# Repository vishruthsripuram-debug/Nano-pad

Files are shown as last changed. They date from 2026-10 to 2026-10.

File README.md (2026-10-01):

# Nano pad
A 4 key macro pad that you can program actions to.
Screenshot 2026-05-01 at 12 41 59 pm

## Design
My inspiration for this macro pad was the printed pad by prota design but i wanted to make something smaller and cheaper than both of their offering the printed pad and glyff. The printed pad being $68 seemed quite unreasonable to me seeing as it was only a screen a few key swicthes and a microcontroller.

I wanted the project to be simple and easily accessible and customisable by many people so all of the PCB design files are included in the rep for download and printing from a pcb service. The case is 3d printable in any colour you like and customisable to include a knob or other features as step and other cad files are included. The model has also been published on makerworld for the ease of use with Bambulab printers. The whole idea is to have a simple good looking macro pad that anyone can own for under $15 USD, for 25 USD you can own 5 macro pads. 

**The design is completely original and simply takes some inspiration fro the prota designs macropad**

## Bill of Materials — Macro Pad

| Item # | Designator | Qty | Manufacturer | Mfg Part # | Description / Value | Package/Footprint | Type | Price Range (AUD / Unit) | Verified Store Links | Notes |
|---|---|---|---|---|---|---|---|---|---|---|
| **1** | SW1, SW2, SW3, SW4 | 4 | Cherry | MX1A-G1NW | MX Brown, tactile, PCB mount, 5-pin | SW_Cherry_MX_1.00u_PCB | THT | $0.40 – $0.88 | [Cafege](https://cafege.com.au "Cherry MX1A-G1NW") <br> [NetNest](https://netnest.com.au "NetNest MX1A-G1NW") <br> [Robot Gear](https://robotgear.com.au "Robot Gear Cherry MX2A Brown") | Sold in packs or individually. Newer MX2A variants are drop-in compatible 5-pin tactile substitutes if the hyperglide variant lacks stock. |
| **2** | U1 | 1 | DFRobot | DFR0648 | Fermion 0.91" 128x32 SSD1306 OLED, I2C, top-mounted pin header (OLED-B) | Module, pin header, THT | THT | $9.90 – $14.50 | [DFRobot Official](https://dfrobot.com "DFRobot DFR0648") <br> [DigiKey](https://digikey.com "DigiKey DFR0648") <br> [Element14 AU](https://element14.com "Element14 DFR0648") | **Double-check pinout prior to soldering**: ensure pins sit on the short top border. |
| **3** | U2 | 1 | Seeed Studio | 101991470 | XIAO ESP32-C6 module (Tape and Reel, SMD variant) | SMD castellated module | SMD | $12.08 – $15.50 | [Pakronics](https://pakronics.com.au "Pakronics Seeed 101991470") <br> [Seeed Studio](https://seeedstudio.com "Seeed Studio 101991470") <br> [RobotShop](https://robotshop.com "RobotShop Seeed 101991470") | Specifically the tape-and-reel edition designed for automated SMT layout without any pre-attached pins. |
| **4** | PCB1 | 1 | Custom | N/A | Main Board PCB | Custom | Board | $1.80 | N/A | Cost per individual board based on production run. |

## Software
software

## Instructions
### Assembly
1. Order the PCB, I ordered with PCBWay and had assembly included.
2. Print out the case.
3. Assemble the PCB, put the OLED into the pin headers and solder it through, Ideally the SMD ESP32 is assembled by PCBWay, but if you can solder SMD then go for it. The keyswitches are through hole solders as well and thats everything.
4. for assembly, insert the board into the case and use m3x 4 BHCS screws to attach the board to the case, the close the lid of the cad, it is a press fit.
5. Click on your keycaps and plug in the macropad

### Flashing
1. Once the board is plugged into your PC, downlaod the code from the github repository, specifically the INO file and open it in Arduino IDE
2. Add ESP32 board support:
File → Preferences → Additional Boards Manager URLs → add:
https://raw.githubusercontent.com/espressif/arduino-esp32/gh-pages/package_esp32_index.json
Tools → Board → Boards Manager → search "esp32" → install "esp32 by Espressif Systems"
3. Select the board
4. Install required libraries (Library Manager, Tools → Manage Libraries):
Adafruit GFX / relevant OLED driver library for your DFRobot module (name it specifically once confirmed)
Any keyboard/HID library
5. Press the upload button and then your done

### Setup
1. Downlaod and open the html file
2. connect your board
3. select the desired functions for your macropad
4. save and uppload
5. exit
6. Youre all done :)

## Schematic and PCB images
Screenshot 2026-09-15 at 11 06 41 AM


## Credits
In collaboration with PCBWay

**PCBWay has financially sponsored the project by providin the parts and assembly free of cost**

The keycaps used in this project are the simple cherry mx keycaps by 3dnerdcave on printables
https://www.printables.com/model/118708-simple-cherry-mx-keycap/files

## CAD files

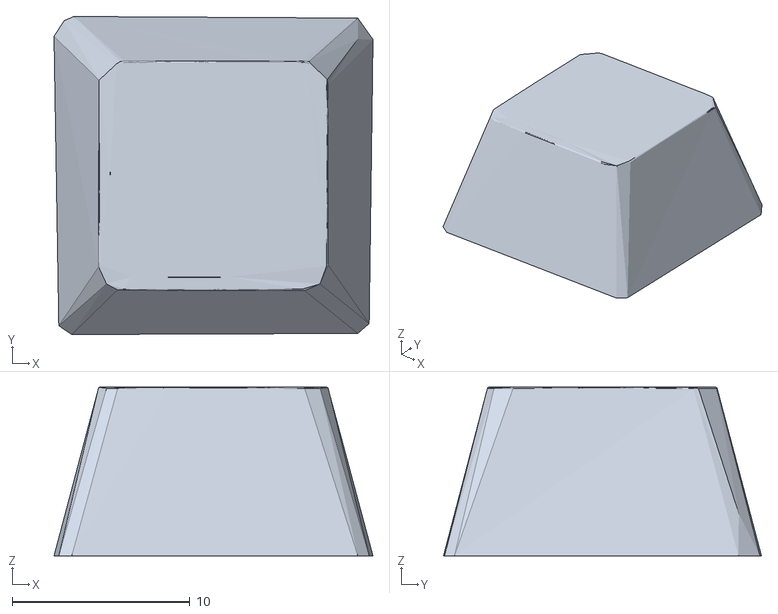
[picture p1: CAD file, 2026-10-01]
3D models/Simple Cherry MX Keycap.stl
18.0 x 17.9 x 9.50

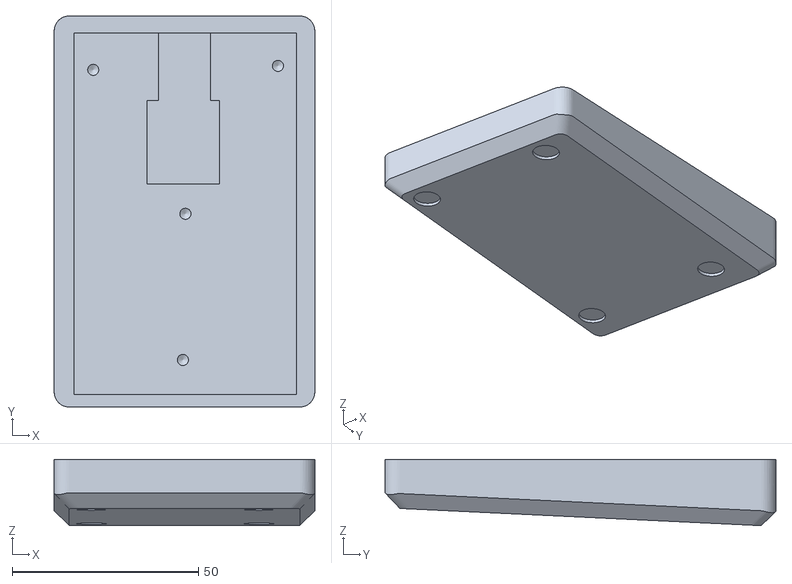
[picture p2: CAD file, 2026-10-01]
3D models/Base.stl
70.0 x 105.0 x 17.8

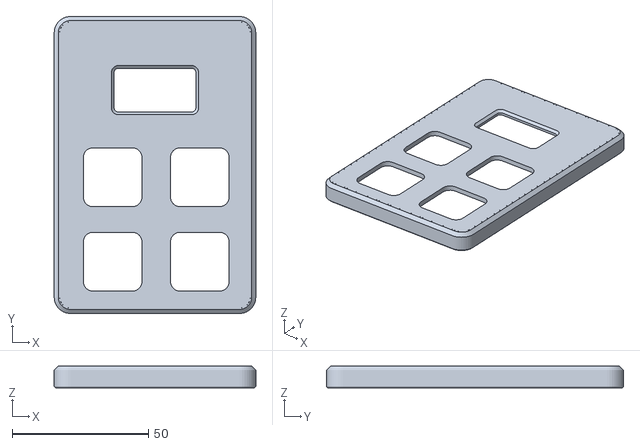
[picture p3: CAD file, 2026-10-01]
3D models/Lid.stl
74.0 x 109.0 x 8.00

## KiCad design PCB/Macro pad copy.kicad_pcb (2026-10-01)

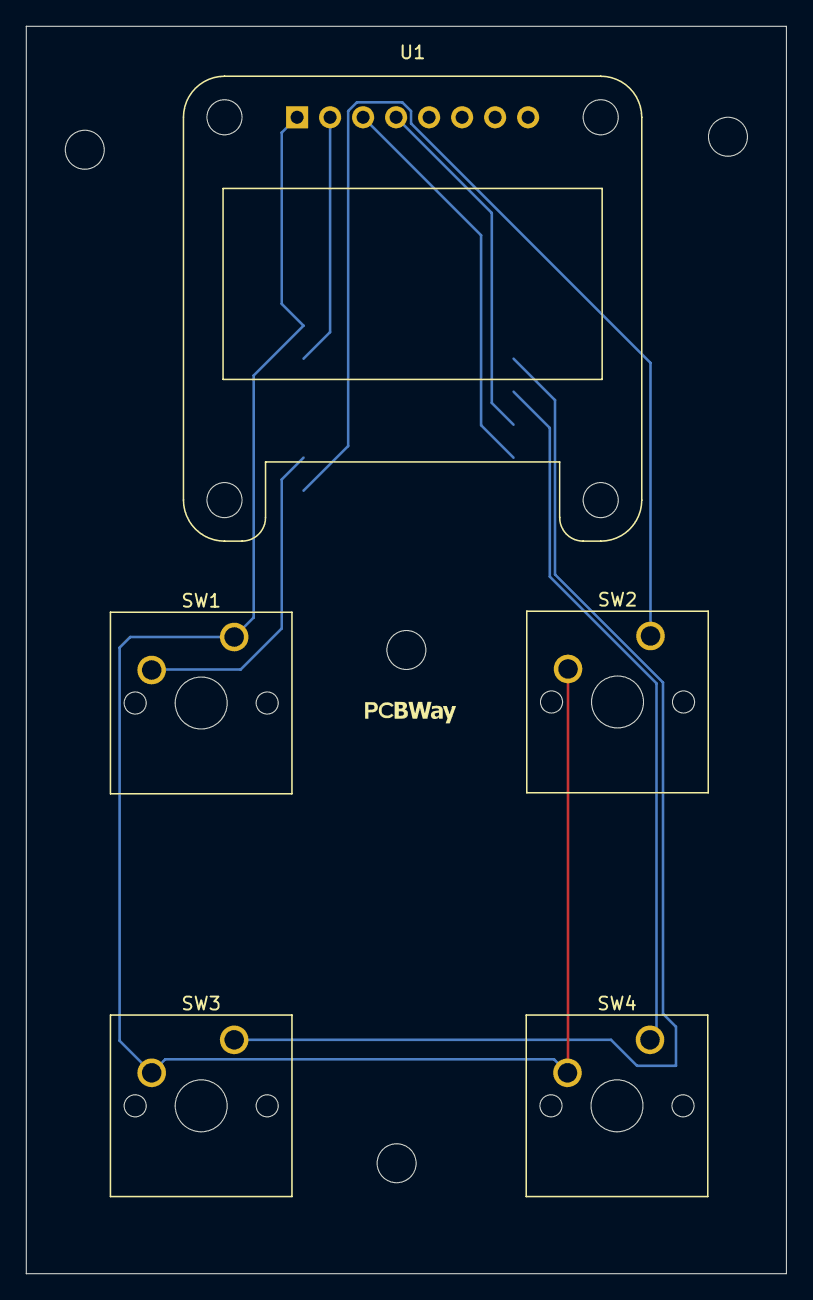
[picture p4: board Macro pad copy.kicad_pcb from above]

Board: 2 copper layers, 58.5 x 96.0 mm, 6 parts (1 on the bottom side), 8 nets.

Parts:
SW1, SW2, SW3, SW4: SW_Push; SW_Cherry_MX_1.00u_PCB
U1: ER_OLEDM0.91_1x-I2C; Adafruit_SSD1306
U2: MOUDLE-SEEEDUINO-XIAO; XIAO-ESP32-C6-SMD

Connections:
GND: SW1.1, SW2.2, SW3.2, SW4.2, U1.1 (GND), U2.13 (GND)
unnamed: U1.3 (SCL), U2.6 (PA9_A5_D5_SCL)
unnamed: U1.4 (SDA), U2.5 (PA8_A4_D4_SDA)
unnamed: U1.2 (VCC), U2.12 (3V3)
unnamed: SW1.2, U2.9 (PA7_A8_D8_SCK)
unnamed: SW3.1, U2.3 (PA10_A2_D2)
unnamed: SW4.1, U2.4 (PA11_A3_D3)
unnamed: SW2.1, U2.8 (PB09_A7_D7_RX)

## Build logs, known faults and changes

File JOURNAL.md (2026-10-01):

# 5/1/2026 - Designing PCB

**Time spent:** 5.5h

PCB Design



Schematic

I first started with the schematic, for the schematic i decided to follow the Hackpad guide for the switches and the microcontroller but i decided to add my own twist which was the screen. The screen is an adafruit oled display with screw mounting holes for mounting onto the PCB. The schematic also included the seeeduino board used in the hackpad guide.

I had to do the schematic twice because for the first time i didnt properly connect the parts together in the schema so in the PCB editor when i was routing the routes weren't connecting.

For the schematic my main concern was with the Tracing. finding the most optimal paths for the lines was incredibly difficult and arranging the traces. The traces were particularly hard to arrange with the ground line but i figured out that i could instead use the same extended ground line essentially piggy backing off of the other ground pins.



*The wiring of the schematic was a bit messy because of the layout i used*

PCB editor

Within the PCB editor is where i designed the main PCB, it took me a while to figure out that i had to assign footprints to the components in the schematic editor. I then placed all of the components in a desirable layout for the macro pad making it simple and good looking fr the macropad. I realised the gap was quite significant when designing in fusion however I was able to fix this after the fact.

The routing was the most significantly difficult part in my opinion it took me multiple attempts and a bunch of tries after deleting multiple routes because the others didn't fit and then, i finally found a layout that would work, but in the DRC it said that my components weren't connected so i check back and realised all my routes were in the top layer of my PCB and not connecting to the microcontroller on the bottom layer, so i had to undo everything and restart from the bottom layer. I realised i could interconnect the ground pins to simplify the layout and reduce the overall wires going to the microcontroller.



After a while of trial and error i eventually figured it out and was able to properly route everything and the DRC showed a fully working PCB, i also learnt about the layers which instructed me to build the pcb frame on the edge cuts layer.

---

# 5/1/2026 - CAD design

**Time spent:** 4.5h

I designed the PCB case in Fusion 360

My inspiration for this macro pad was the printed pad by Prota design but i wanted to make something smaller and cheaper than both of their offering the printed pad and glyff.

Step 1

I first exported the step file of my PC into fusion by exporting out of KIcad, here i encountered some errors explained in the previous journal entry where my routing want correct and the DRC wasnt approving my project to be exported due to those errors. Eventually i figured it out and exported it as a step file into fusion 360 where i opened a hybrid design file.

Chellenge
The main challenge with the cad was making it look nice. The Macropad had to be simple and look nice, which was a key requirement. When i designed it it had smooth chamfers and fillets to reflect the design language i was aiming for. The black design refelcts the prota pad well. Further when designing i had to allow ample clearance between the keycaps for them to glide smoothly into the macropad when clicking. 

Finding the correct Cad files for the 



After importing everything into fusion i started the creation of my case for the macro pad PCB. So far i have the PCB laid in the frame with switches laid on top. The switches are cherry mx red switches which provide a satisfying clicking experience had smooth travel. I placed the switches onto the PCB and they fit perfectly.

Whats left

I still have to make a cutout for the microcontroller mounted on the bottom and another cutout for the USB-C cord which provides power and signal to the macro pad.

I also have to design the top shell of the case similar to the Prota design case.

---

# 5/1/2026 - More fusion - Designing lid and adding keycaps

**Time spent:** 3.5h

In the previous journal entry i said that i would complete the Lid and add the USB charging port and thats what i did.

I designed the lid simply by just creating a sketch on top of the base and creating a 2mm offset for a sturdy but light feel. The holes for the keyswitches have decent clearance for the kycaps to go beneath the top layer for full travel. Cherry mx switches can detect travel amount so i plan to use this in firmware.



---

# 5/1/2026 - I developed the code and editing software for the macropad

I coded the app for editing the macro pad there are multiple options for holding, double clicking and single pressing, there are also sliders to update these settings.

OLED screen modes

- Laptop battery percentage
- Volume level
- WiFi strength
- CPU temperature
- Custom text
- Uploaded images
- A virtual pet

Web configurator coding

I used CSS for the styles, JS and HTML.

The configurator includes a live preview of the OLED inside the SVG macropad.



**Time spent:** 2.5h

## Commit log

2026-09-15 Add schematic and PCB images to README
    Added schematic and PCB images section with images.
2026-10-01 Update README with new images and sponsorship info
    Updated images and added collaboration note with PCBWay.
